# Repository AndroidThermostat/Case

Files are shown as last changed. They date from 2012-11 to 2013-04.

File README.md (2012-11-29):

Case
====

A printable 3d model of a case that can be used with the Android Thermostat project.

**Important** Make sure the case you print matches the revision number on the assembly instructions.

License
-------

CERN OPEN HARDWARE LICENCE v1.1

Preamble

Through this CERN Open Hardware Licence ("CERN OHL") version 1.1, the
Organization wishes to disseminate its hardware designs (as published
on http://www.ohwr.org/) as widely as possible, and generally to
foster collaboration among public research hardware designers.  The
CERN OHL is copyright of CERN. Anyone is welcome to use the CERN OHL,
in unmodified form only, for the distribution of his own Open Hardware
designs. Any other right is reserved.  

1 Definitions

In this Licence, the following terms have the following meanings:

“Licence” means this CERN OHL.  

“Documentation” means schematic diagrams, designs, circuit or circuit
board layouts, mechanical drawings, flow charts and descriptive text,
and other explanatory material that is explicitly stated as being made
available under the conditions of this Licence. The Documentation may
be in any medium, including but not limited to computer files and
representations on paper, film, or any other media.  

“Product” means either an entire, or any part of a, device built using
the Documentation or the modified Documentation.  

“Licensee” means any natural or legal person exercising rights under
this Licence.  

“Licensor” means any natural or legal person that creates or modifies
Documentation and subsequently communicates to the public and/ or
distributes the resulting Documentation under the terms and conditions
of this Licence.  

A Licensee may at the same time be a Licensor, and vice versa.

2 Applicability

2.1 This Licence governs the use, copying, modification, communication
to the public and distribution of the Documentation, and the
manufacture and distribution of Products. By exercising any right
granted under this Licence, the Licensee irrevocably accepts these
terms and conditions.  

2.2 This Licence is granted by the Licensor directly to the Licensee,
and shall apply worldwide and without limitation in time. The Licensee
may assign his licence rights or grant sub-licences.  

2.3 This Licence does not apply to software, firmware, or code loaded
into programmable devices which may be used in conjunction with the
Documentation, the modified Documentation or with Products. The use of
such software, firmware, or code is subject to the applicable licence
terms and conditions.  

3 Copying, modification, communication to the public and distribution
of the Documentation

3.1 The Licensee shall keep intact all copyright and trademarks
notices and all notices that refer to this Licence and to the
disclaimer of warranties that is included in the Documentation. He
shall include a copy thereof in every copy of the Documentation or, as
the case may be, modified Documentation, that he communicates to the
public or distributes.

3.2 The Licensee may use, copy, communicate to the public and
distribute verbatim copies of the Documentation, in any medium,
subject to the requirements specified in section 3.1.

3.3 The Licensee may modify the Documentation or any portion
thereof. The Licensee may communicate to the public and distribute the
modified Documentation (thereby in addition to being a Licensee also
becoming a Licensor), always provided that he shall: 
a. comply with section 3.1;
b. cause the modified Documentation to carry prominent notices stating
that the Licensee has modified the Documentation, with the date and
details of the modifications;
c. license the modified Documentation under the terms and conditions
of this Licence or, where applicable, a later version of this Licence
as may be issued by CERN; and
d. send a copy of the modified Documentation to all Licensors that
contributed to the parts of the Documentation that were modified, as
well as to any other Licensor who has requested to receive a copy of
the modified Documentation and has provided a means of contact with
the Documentation.

3.4 The Licence includes a licence to those patents or registered
designs that are held by the Licensor, to the extent necessary to make
use of the rights granted under this Licence. The scope of this
section 3.4 shall be strictly limited to the parts of the
Documentation or modified Documentation created by the Licensor.

4 Manufacture and distribution of Products

4.1 The Licensee may manufacture or distribute Products always
provided that the Licensee distributes to each recipient of such
Products a copy of the Documentation or modified Documentation, as
applicable, and complies with section 3.

4.2 The Licensee is invited to inform in writing any Licensor who has
indicated its wish to receive this information about the type,
quantity and dates of production of Products the Licensee has (had)
manufactured.

5 Warranty and liability

5.1 DISCLAIMER – The Documentation and any modified Documentation are
provided "as is" and any express or implied warranties, including, but
not limited to, implied warranties of merchantability, of satisfactory
quality, and fitness for a particular purpose or use are disclaimed in
respect of the Documentation, the modified Documentation or any
Product. The Licensor makes no representation that the Documentation,
modified Documentation, or any Product, does or will not infringe any
patent, copyright, trade secret or other proprietary right. The entire
risk as to the use, quality, and performance of a Product shall be
with the Licensee and not the Licensor. This disclaimer of warranty is
an essential part of this Licence and a condition for the grant of any
rights granted under this Licence. The Licensee warrants that it does
not act in a consumer capacity.

5.2 LIMITATION OF LIABILITY – The Licensor shall have no liability for
direct, indirect, special, incidental, consequential, exemplary,
punitive or other damages of any character including, without
limitation, procurement of substitute goods or services, loss of use,
data or profits, or business interruption, however caused and on any
theory of contract, warranty, tort (including negligence), product
liability or otherwise, arising in any way in relation to the
Documentation, modified Documentation and/or the use, manufacture or
distribution of a Product, even if advised of the possibility of such
damages, and the Licensee shall hold the Licensor(s) free and harmless
from any liability, costs, damages, fees and expenses, including
claims by third parties, in relation to such use.

6 General

6.1 The rights granted under this Licence do not imply or represent
any transfer or assignment of intellectual property rights to the
Licensee.

6.2 The Licensee shall not use or make reference to any of the names,
acronyms, images or logos under which the Licensor is known, save in
so far as required to comply with section 3. Any such permitted use or
reference shall be factual and shall in no event suggest any kind of
endorsement by the Licensor or its personnel of the modified
Documentation or any Product, or any kind of implication by the
Licensor or its personnel in the preparation of the modified
Documentation or Product.

6.3 CERN may publish updated versions of this Licence which retain the
same general provisions as this version, but differ in detail so far
this is required and reasonable. New versions will be published with a
unique version number.

6.4 This Licence shall terminate with immediate effect, upon written
notice and without involvement of a court if the Licensee fails to
comply with any of its terms and conditions, or if the Licensee
initiates legal action against Licensor in relation to this
Licence. Section 5 shall continue to apply.

6.5 Except as may be otherwise agreed with the Intergovernmental
Organization, any dispute with respect to this Licence involving an
Intergovernmental Organization shall, by virtue of the latter's
Intergovernmental status, be settled by international arbitration. The
arbitration proceedings shall be held at the place where the
Intergovernmental Organization has its seat. The arbitral award shall
be final and binding upon the parties, who hereby expressly agree to
renounce any form of appeal or revision.

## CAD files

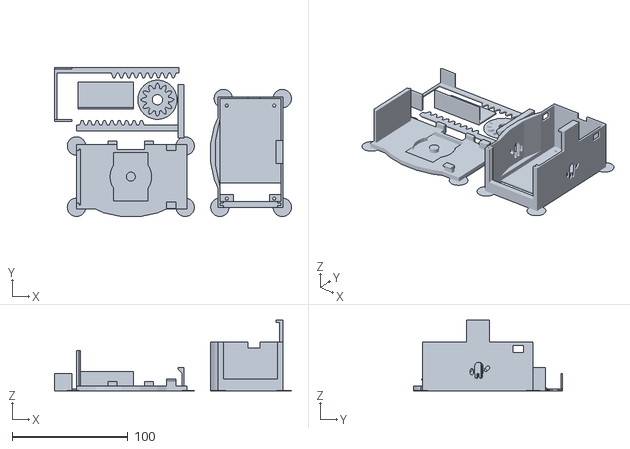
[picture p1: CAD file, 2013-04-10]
Revision B/STL/Full.stl
204.9 x 129.1 x 61.0

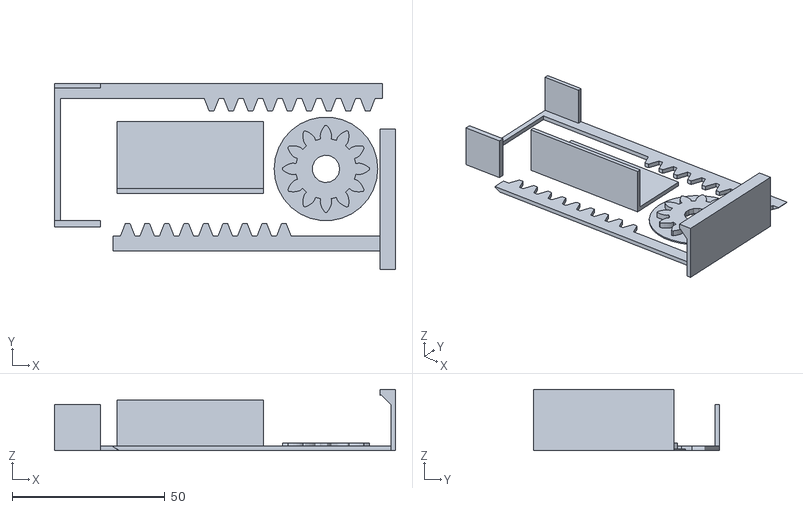
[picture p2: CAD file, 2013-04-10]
Revision B/STL/Rack.stl
111.8 x 61.0 x 20.0

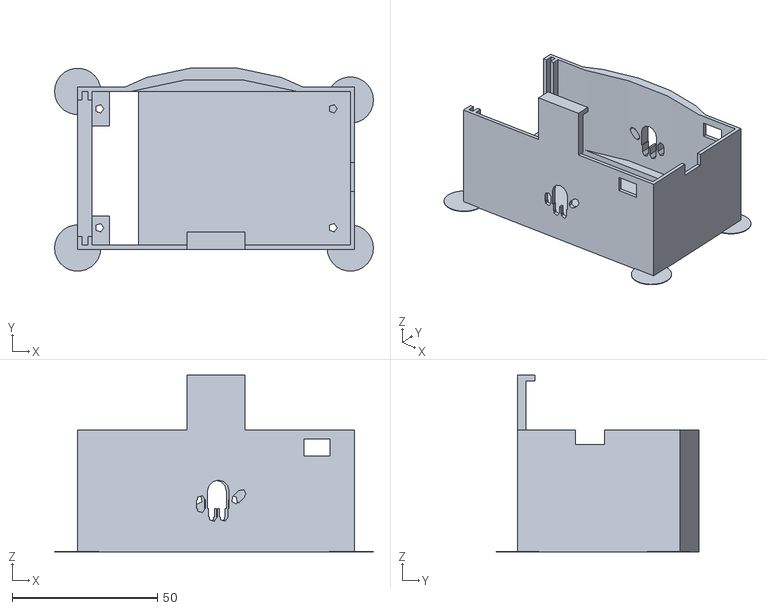
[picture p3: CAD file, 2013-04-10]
Revision B/STL/Case.stl
110.0 x 70.0 x 61.0

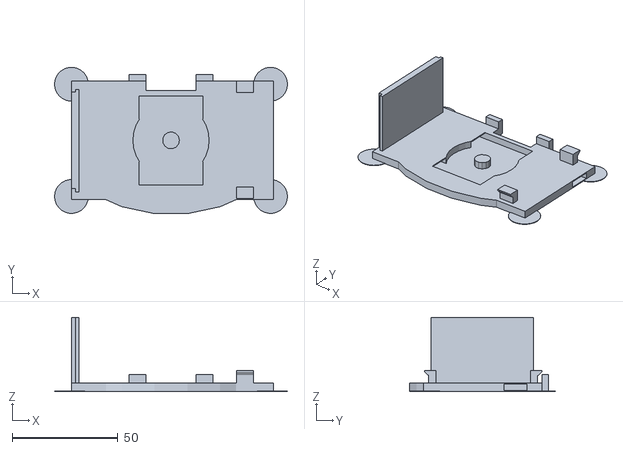
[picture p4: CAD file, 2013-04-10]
Revision B/STL/Lid.stl
110.0 x 69.0 x 35.0

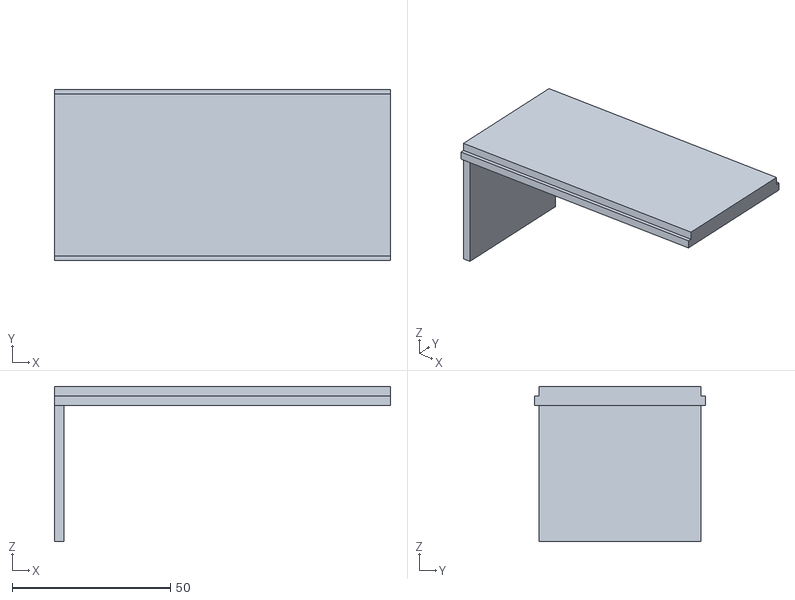
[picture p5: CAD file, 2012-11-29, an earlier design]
Revision A/CaseTop.stl
106.0 x 54.0 x 49.0

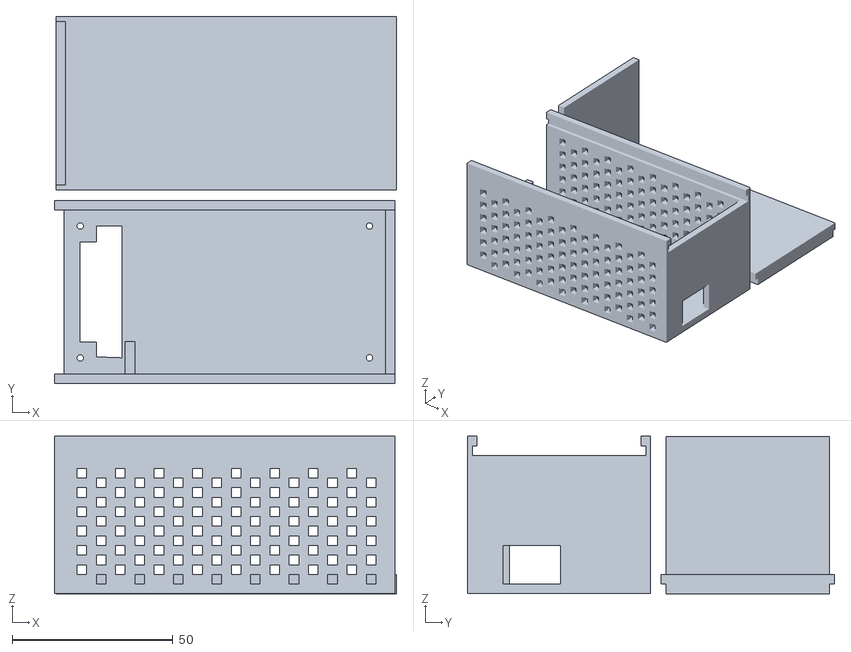
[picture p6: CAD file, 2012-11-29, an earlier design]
Revision A/CaseBoth.stl
106.4 x 114.2 x 49.0

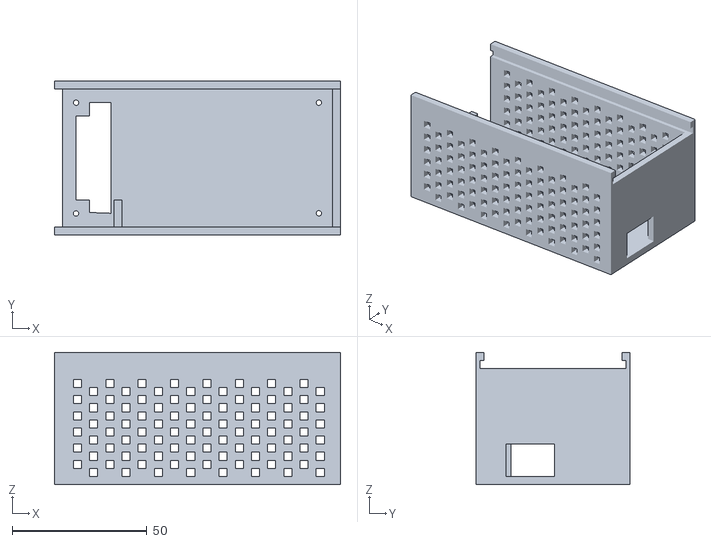
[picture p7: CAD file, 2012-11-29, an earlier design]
Revision A/CaseBottom.stl
106.0 x 57.0 x 49.0

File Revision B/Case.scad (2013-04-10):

include <gearLib.scad>

caseLength=94;
caseWidth=53;
caseHeight = 42; //36
wallThickness = 1.5;

//**********************************Lid***************************************************
module drawLidBase(x,y,z)
{
	translate([x, y-wallThickness, z]) cube([caseLength + wallThickness,caseWidth + (wallThickness*2),4]);

	//pads to help prevent pealing
	translate([x, y, z]) cylinder(h = 0.2,r = 8);
	translate([x, y+caseWidth, z]) cylinder(h = 0.2,r = 8);
	translate([x+caseLength, y, z]) cylinder(h = 0.2,r = 8);
	translate([x+caseLength, y+caseWidth, z]) cylinder(h = 0.2,r = 8);

	//lip
	translate([x+2, y+2, z+4]) cube ([1.5,caseWidth-4.5,caseHeight-11]);
	translate([x, y+3.75, z+4]) cube ([2,caseWidth-7.5,caseHeight-11]);


	//Catches
	difference()
	{
		translate([x+caseLength-16,y-1,z+4]) cube([8,5.5,6]);
		translate([x+caseLength-16,y-1,z+4]) cube([8,2,3.9]);
		translate([x+caseLength-16,y-1.7,z+5.8]) rotate([45,0,0]) cube([8,3,3]);
	}

	difference()
	{
		translate([x+caseLength-16,y + caseWidth - 4,z+4]) cube([8,5.5,6]);
		translate([x+caseLength-16,y + caseWidth - 0.5,z+4]) cube([8,2,3.5]);
		translate([x+caseLength-16,y + caseWidth + 1.7, z+5.4]) rotate([45,0,0]) cube([8,3,3]);
	}

	//draw the curved top
	difference()
	{
		translate([x+caseLength/2,y+caseWidth+13.7,z]) cylinder(h = 4,r = caseLength*0.8);
		translate([x-caseLength/2,y-caseLength+100,z]) cube([caseLength*2,caseLength*2+10,4]);
	}

	translate([x+(caseLength+23.5)/2,  y+ caseWidth+wallThickness , z]) cube([8,3,8]);
	translate([x+(caseLength-23.5)/2-8,  y+ caseWidth+wallThickness , z]) cube([8,3,8]);
}

module drawLidCutouts(x,y,z)
{
	//Gear hole
	translate([x+(caseLength/2), y+(caseWidth/2), z+0.5]) cylinder(h = 3.5,r = 18);

	//Top Rail
	translate([x, y+(caseWidth/2 - 21), z+0.5]) cube([caseLength-wallThickness,11,3]);
	translate([x+(caseLength-30)/2, y+(caseWidth/2 - 21), z+3]) cube([30,11,1]);

	//Bottom Rail
	translate([x+5, y+(caseWidth/2 + 10), z+0.5]) cube([caseLength-wallThickness,11,3]);
	translate([x+(caseLength-30)/2, y+(caseWidth/2 + 10), z+3]) cube([30,11,1]);

	//Cutout for lip
	translate([x+(caseLength-23.5)/2, y+ caseWidth - 3, z]) cube([23.5,4.5,4]);
}

module drawLid(x,y,z)
{
	difference()
	{
		drawLidBase(x,y,z);
		drawLidCutouts(x,y,z);
	}
	translate([x+(caseLength/2),y+(caseWidth/2),z+0.5]) cylinder(h = 3.5,r = 4);
}



//*****************************Rack and Pinion*******************************************

module drawGear(x,y,z)
{
	difference() 
	{
		translate([x,y,z]) cylinder(h = 0.5,r = 17);
		translate([x,y,z]) cylinder(h = 0.5,r = 5);
	}
	//12.23 radius  -   circular_pitch * number_of_teeth / 360
	translate([x, y, z+0.5]) gear(number_of_teeth=12, circular_pitch=367, hub_thickness=0, bore_diameter=9,rim_thickness=2, gear_thickness=2);
}

module drawLeftRack(x,y,z)
{
	//mm_per_tooth = 2 * Pi * r / gear_teeth
	difference()
	{
		translate([x+caseLength-106,y,z+(1.5/2)]) rack(height=9, mm_per_tooth=6.4, number_of_teeth=9, thickness=wallThickness);
		translate([x+caseLength-106-7.5,y-7,z+1.5-4.5]) rotate([0,30,0])  cube ([5,5,5]); //Angle tip
		//translate([x,y,z+(1.5/2)]) rack(height=9, mm_per_tooth=6.4, number_of_teeth=9, thickness=wallThickness);
		//translate([x-7.5,y-7,z+1.5-4.5]) rotate([0,30,0])  cube ([5,5,5]); //Angle tip
	}

	translate([x+(caseLength-50),y-7,z]) cube([(caseLength-63.7),5,wallThickness]);
	translate([x+(caseLength-50 + caseLength-63.7),y-8-5,z]) cube([wallThickness,46,15]);
	difference(){
		translate([x+(caseLength-50 + caseLength-63.7)-5+wallThickness,y-8-5,z+15]) cube([5,46,5]);
		translate([x+(caseLength-50 + caseLength-63.7)-wallThickness,y-8-5,z+13]) rotate([0,315,0]) cube([2.5,46,5]);
	}
}

module drawRightRackCap(x,y,z)
{
	translate([x+5,y-49.5,z]) cube([23.5,48,1.5]);
	translate([x+5,y-49.5,z+1.5]) cube([1.5,48,15]);
}

module drawRightRack(x,y,z)
{
	difference()
	{
		translate([x+(caseLength-6.3),y,z+(1.5/2)]) rotate([0,0,180]) rack(height=9, mm_per_tooth=6.4, number_of_teeth=9, thickness=wallThickness);
		translate([x+(caseLength-3.8),y,z]) rotate([0,60,0])  cube ([5,15,5]); //Angle tip
	}


	translate([x,y+2,z]) cube([caseLength-59.7,5,1.5]);

	difference()
	{
		translate([x-15,y-51+11,z]) cube([15,47,15]);
		translate([x-15,y-51+13,z+wallThickness]) cube([15,43.5,78]);
		translate([x-13,y-51+13,z]) cube([13,40,8]);
	}

}





//*****************************Case***************************************************

module drawLogo(x,y,z)
{
	union() {
		translate([x,y,z])  rotate([90,0,0]) cylinder(h = wallThickness*4,r = 3.75);

		translate([x-3.75,y-wallThickness*4,z-6])  cube([7.5,wallThickness*4,6]);
		translate([x-6,y,z-3])  rotate([90,0,0]) drawLogoExtremity();
		translate([x-1.875,y,z-6])  rotate([90,0,0]) drawLogoExtremity();
		translate([x+1.875,y,z-6])  rotate([90,0,0]) drawLogoExtremity();
		translate([x+6,y,z-3])  rotate([90,225,0]) drawLogoExtremity();
	}
}

module drawLogoExtremity()
{
	cylinder(h = wallThickness*4,r = 1.5);
	translate([-1.5,-3,0]) cube([3,3,wallThickness*4]);
	translate([0,-3,0]) cylinder(h = wallThickness*4,r = 1.5);
}

module drawCase(x,y,z)
{
	stepsH=(caseHeight-11)/6;
	stepsL=(caseLength-12)/12;

	//pads to help prevent pealing
	translate([x, y+2, z]) cylinder(h = 0.2,r = 8);
	translate([x+caseLength, y+2, z]) cylinder(h = 0.2,r = 8);
	translate([x, y+caseWidth+(wallThickness*2), z]) cylinder(h = 0.2,r = 8);
	translate([x+caseLength, y+caseWidth, z]) cylinder(h = 0.2,r = 8);

	difference()
	{
		//Bottom and screw holes
		translate([x,y+(wallThickness*2),z]) cube([caseLength,caseWidth,wallThickness]);

		translate([x+wallThickness+6,y+(wallThickness*2)+6,z]) cylinder(h = wallThickness,r = 1.5);
		translate([x+wallThickness+6,y+caseWidth+(wallThickness*2)-6,z]) cylinder(h = wallThickness,r = 1.5);
		translate([x+caseLength-6,y+(wallThickness*2)+6,z]) cylinder(h = wallThickness,r = 1.5);
		translate([x+caseLength-6,y+caseWidth+(wallThickness*2)-6,z]) cylinder(h = wallThickness,r = 1.5);

		//Hole for furnace wires
		translate([x+(wallThickness*2),y+13,z]) cube([8,31,wallThickness]);
		translate([x+(wallThickness*2)+8,y+(wallThickness*2),z]) cube([10,caseWidth,wallThickness]);
	}


	//Side walls
	difference() {
		union(){
			translate([x,y+wallThickness,z]) cube([caseLength,wallThickness,caseHeight]);
			translate([x,y+caseWidth+(wallThickness*2),z]) cube([caseLength,wallThickness,caseHeight]);

			//draw the curved top
			difference()
			{
				translate([x+caseLength/2,y-10.7,z]) cylinder(h = caseHeight,r = caseLength*0.8);
				translate([x-caseLength/2,y-caseLength-(caseLength/2),z]) cube([caseLength*2,caseLength*2+10,caseHeight]);
			}
		}

		//Cut away the inside of the curved top
		difference()
		{
//			translate([x+caseLength/2,y-32-wallThickness,z+wallThickness]) cylinder(h = caseHeight-wallThickness,r = caseLength);
			translate([x+caseLength/2,y-32-wallThickness,z+wallThickness+4]) cylinder(h = caseHeight-wallThickness,r = caseLength);
			translate([x-caseLength/2,y-caseLength-(caseLength/2)-wallThickness,z]) cube([caseLength*2,caseLength*2+10,caseHeight]);
		}


		drawLogo(x+(caseLength/2)+1.5,y+4,z+(wallThickness*2)+18);
		rotate([0,0,180]) drawLogo(-x-(caseLength/2)-0.5,-y-caseWidth-wallThickness*2-3,z+(wallThickness*2)+18);

		//Lid catches		
		 translate([x+caseLength-16,y,z+caseHeight-9]) cube([9,3,6]);
		 translate([x+caseLength-16,y+caseWidth+(wallThickness*2),z+caseHeight-9]) cube([9,3,6]);
	}

	//board catch	
//	translate([x,y+caseWidth+(wallThickness*2),z]) cube([caseLength,wallThickness,8]);

	//back wall
	difference()
	{
		translate([x+caseLength,y+wallThickness,z]) cube([wallThickness,caseWidth+(wallThickness*2),caseHeight]);
		translate([x+caseLength,y+(caseWidth-10)/2, caseHeight-5]) cube([wallThickness,10,5]);
//		translate([x+caseLength-wallThickness,y+caseWidth/2,caseHeight-4]) rotate([0,90,0]) cylinder(h = wallThickness*2,r = 4);
	}


	//Lip
	difference()
	{
		translate([x+(caseLength-18.5)/2,y+wallThickness,z+caseHeight-wallThickness]) cube([20,wallThickness*2,17+wallThickness]);
		translate([x+(caseLength-18.5)/2,y+wallThickness*2+1,z+caseHeight-wallThickness-1]) rotate([45,0,0]) cube([20,wallThickness*2,wallThickness]);
	}

	translate([x+(caseLength-18.5)/2,y+wallThickness,z+caseHeight+17]) cube([20,3*2,2]);

	//Grooves
	difference()
	{
		translate([x,y+(wallThickness*2),z]) cube([5,3,caseHeight]);
		translate([x+wallThickness,y+(wallThickness*2),z]) cube([2,3,caseHeight]);
	}
	difference()
	{
		translate([x,y+caseWidth,z]) cube([5,3,caseHeight]);
		translate([x+wallThickness,y+caseWidth,z]) cube([2,3,caseHeight]);
	}

	translate([x,y+(wallThickness*2),z]) cube([5,caseWidth,10]);

}








//*****************************Combinations**********************************************


module drawAssembled(x,y,z)
{
	drawCase(x,y,z);
	rotate([180,0,0]) drawLidAssembled(x,y-54,-z - 40);
}
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

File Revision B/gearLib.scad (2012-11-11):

// Parametric Involute Bevel and Spur Gears by GregFrost
// It is licensed under the Creative Commons - GNU GPL license.
// © 2010 by GregFrost
// http://www.thingiverse.com/thing:3575

// Simple Test:
//gear (circular_pitch=700,
//	gear_thickness = 12,
//	rim_thickness = 15,
//	hub_thickness = 17,
//	circles=8);

//Complex Spur Gear Test:
//test_gears ();

// Meshing Double Helix:
//meshing_double_helix ();

// Demonstrate the backlash option for Spur gears.
//test_backlash ();

// Demonstrate how to make meshing bevel gears.
//bevel_gear_pair ();

pi=3.1415926535897932384626433832795;

//==================================================
// Bevel Gears:
// Two gears with the same cone distance, circular pitch (measured at the cone distance) 
// and pressure angle will mesh.

module bevel_gear_pair (
	gear1_teeth = 41,
	gear2_teeth = 7,
	axis_angle = 90,
	outside_circular_pitch=1000)
{
	outside_pitch_radius1 = gear1_teeth * outside_circular_pitch / 360;
	outside_pitch_radius2 = gear2_teeth * outside_circular_pitch / 360;
	pitch_apex1=outside_pitch_radius2 * sin (axis_angle) + 
		(outside_pitch_radius2 * cos (axis_angle) + outside_pitch_radius1) / tan (axis_angle);
	cone_distance = sqrt (pow (pitch_apex1, 2) + pow (outside_pitch_radius1, 2));
	pitch_apex2 = sqrt (pow (cone_distance, 2) - pow (outside_pitch_radius2, 2));
	echo ("cone_distance", cone_distance);
	pitch_angle1 = asin (outside_pitch_radius1 / cone_distance);
	pitch_angle2 = asin (outside_pitch_radius2 / cone_distance);
	echo ("pitch_angle1, pitch_angle2", pitch_angle1, pitch_angle2);
	echo ("pitch_angle1 + pitch_angle2", pitch_angle1 + pitch_angle2);

	rotate([0,0,90])
	translate ([0,0,pitch_apex1+20])
	{
		translate([0,0,-pitch_apex1])
		bevel_gear (
			number_of_teeth=gear1_teeth,
			cone_distance=cone_distance,
			pressure_angle=30,
			outside_circular_pitch=outside_circular_pitch);
	
		rotate([0,-(pitch_angle1+pitch_angle2),0])
		translate([0,0,-pitch_apex2])
		bevel_gear (
			number_of_teeth=gear2_teeth,
			cone_distance=cone_distance,
			pressure_angle=30,
			outside_circular_pitch=outside_circular_pitch);
	}
}

//Bevel Gear Finishing Options:
bevel_gear_flat = 0;
bevel_gear_back_cone = 1;

module bevel_gear (
	number_of_teeth=11,
	cone_distance=100,
	face_width=20,
	outside_circular_pitch=1000,
	pressure_angle=30,
	clearance = 0.2,
	bore_diameter=5,
	gear_thickness = 15,
	backlash = 0,
	involute_facets=0,
	finish = -1)
{
	echo ("bevel_gear",
		"teeth", number_of_teeth,
		"cone distance", cone_distance,
		face_width,
		outside_circular_pitch,
		pressure_angle,
		clearance,
		bore_diameter,
		involute_facets,
		finish);

	// Pitch diameter: Diameter of pitch circle at the fat end of the gear.
	outside_pitch_diameter  =  number_of_teeth * outside_circular_pitch / 180;
	outside_pitch_radius = outside_pitch_diameter / 2;

	// The height of the pitch apex.
	pitch_apex = sqrt (pow (cone_distance, 2) - pow (outside_pitch_radius, 2));
	pitch_angle = asin (outside_pitch_radius/cone_distance);

	echo ("Num Teeth:", number_of_teeth, " Pitch Angle:", pitch_angle);

	finish = (finish != -1) ? finish : (pitch_angle < 45) ? bevel_gear_flat : bevel_gear_back_cone;

	apex_to_apex=cone_distance / cos (pitch_angle);
	back_cone_radius = apex_to_apex * sin (pitch_angle);

	// Calculate and display the pitch angle. This is needed to determine the angle to mount two meshing cone gears.

	// Base Circle for forming the involute teeth shape.
	base_radius = back_cone_radius * cos (pressure_angle);	

	// Diametrial pitch: Number of teeth per unit length.
	pitch_diametrial = number_of_teeth / outside_pitch_diameter;

	// Addendum: Radial distance from pitch circle to outside circle.
	addendum = 1 / pitch_diametrial;
	// Outer Circle
	outer_radius = back_cone_radius + addendum;

	// Dedendum: Radial distance from pitch circle to root diameter
	dedendum = addendum + clearance;
	dedendum_angle = atan (dedendum / cone_distance);
	root_angle = pitch_angle - dedendum_angle;

	root_cone_full_radius = tan (root_angle)*apex_to_apex;
	back_cone_full_radius=apex_to_apex / tan (pitch_angle);

	back_cone_end_radius = 
		outside_pitch_radius - 
		dedendum * cos (pitch_angle) - 
		gear_thickness / tan (pitch_angle);
	back_cone_descent = dedendum * sin (pitch_angle) + gear_thickness;

	// Root diameter: Diameter of bottom of tooth spaces.
	root_radius = back_cone_radius - dedendum;

	half_tooth_thickness = outside_pitch_radius * sin (360 / (4 * number_of_teeth)) - backlash / 4;
	half_thick_angle = asin (half_tooth_thickness / back_cone_radius);

	face_cone_height = apex_to_apex-face_width / cos (pitch_angle);
	face_cone_full_radius = face_cone_height / tan (pitch_angle);
	face_cone_descent = dedendum * sin (pitch_angle);
	face_cone_end_radius = 
		outside_pitch_radius -
		face_width / sin (pitch_angle) - 
		face_cone_descent / tan (pitch_angle);

	// For the bevel_gear_flat finish option, calculate the height of a cube to select the portion of the gear that includes the full pitch face.
	bevel_gear_flat_height = pitch_apex - (cone_distance - face_width) * cos (pitch_angle);

//	translate([0,0,-pitch_apex])
	difference ()
	{
		intersection ()
		{
			union()
			{
				rotate (half_thick_angle)
				translate ([0,0,pitch_apex-apex_to_apex])
				cylinder ($fn=number_of_teeth*2, r1=root_cone_full_radius,r2=0,h=apex_to_apex);
				for (i = [1:number_of_teeth])
//				for (i = [1:1])
				{
					rotate ([0,0,i*360/number_of_teeth])
					{
						involute_bevel_gear_tooth (
							back_cone_radius = back_cone_radius,
							root_radius = root_radius,
							base_radius = base_radius,
							outer_radius = outer_radius,
							pitch_apex = pitch_apex,
							cone_distance = cone_distance,
							half_thick_angle = half_thick_angle,
							involute_facets = involute_facets);
					}
				}
			}

			if (finish == bevel_gear_back_cone)
			{
				translate ([0,0,-back_cone_descent])
				cylinder (
					$fn=number_of_teeth*2, 
					r1=back_cone_end_radius,
					r2=back_cone_full_radius*2,
					h=apex_to_apex + back_cone_descent);
			}
			else
			{
				translate ([-1.5*outside_pitch_radius,-1.5*outside_pitch_radius,0])
				cube ([3*outside_pitch_radius,
					3*outside_pitch_radius,
					bevel_gear_flat_height]);
			}
		}
		
		if (finish == bevel_gear_back_cone)
		{
			translate ([0,0,-face_cone_descent])
			cylinder (
				r1=face_cone_end_radius,
				r2=face_cone_full_radius * 2,
				h=face_cone_height + face_cone_descent+pitch_apex);
		}

		translate ([0,0,pitch_apex - apex_to_apex])
		cylinder (r=bore_diameter/2,h=apex_to_apex);
	}	
}

module involute_bevel_gear_tooth (
	back_cone_radius,
	root_radius,
	base_radius,
	outer_radius,
	pitch_apex,
	cone_distance,
	half_thick_angle,
	involute_facets)
{
//	echo ("involute_bevel_gear_tooth",
//		back_cone_radius,
//		root_radius,
//		base_radius,
//		outer_radius,
//		pitch_apex,
//		cone_distance,
//		half_thick_angle);

	min_radius = max (base_radius*2,root_radius*2);

	pitch_point = 
		involute (
			base_radius*2, 
			involute_intersect_angle (base_radius*2, back_cone_radius*2));
	pitch_angle = atan2 (pitch_point[1], pitch_point[0]);
	centre_angle = pitch_angle + half_thick_angle;

	start_angle = involute_intersect_angle (base_radius*2, min_radius);
	stop_angle = involute_intersect_angle (base_radius*2, outer_radius*2);

	res=(involute_facets!=0)?involute_facets:($fn==0)?5:$fn/4;

	translate ([0,0,pitch_apex])
	rotate ([0,-atan(back_cone_radius/cone_distance),0])
	translate ([-back_cone_radius*2,0,-cone_distance*2])
	union ()
	{
		for (i=[1:res])
		{
			assign (
				point1=
					involute (base_radius*2,start_angle+(stop_angle - start_angle)*(i-1)/res),
				point2=
					involute (base_radius*2,start_angle+(stop_angle - start_angle)*(i)/res))
			{
				assign (
					side1_point1 = rotate_point (centre_angle, point1),
					side1_point2 = rotate_point (centre_angle, point2),
					side2_point1 = mirror_point (rotate_point (centre_angle, point1)),
					side2_point2 = mirror_point (rotate_point (centre_angle, point2)))
				{
					polyhedron (
						points=[
							[back_cone_radius*2+0.1,0,cone_distance*2],
							[side1_point1[0],side1_point1[1],0],
							[side1_point2[0],side1_point2[1],0],
							[side2_point2[0],side2_point2[1],0],
							[side2_point1[0],side2_point1[1],0],
							[0.1,0,0]],
						triangles=[[0,1,2],[0,2,3],[0,3,4],[0,5,1],[1,5,2],[2,5,3],[3,5,4],[0,4,5]]);
				}
			}
		}
	}
}

module gear (
	number_of_teeth=15,
	circular_pitch=false, diametral_pitch=false,
	pressure_angle=28,
	clearance = 0.2,
	gear_thickness=5,
	rim_thickness=8,
	rim_width=5,
	hub_thickness=10,
	hub_diameter=15,
	bore_diameter=5,
	circles=0,
	backlash=0,
	twist=0,
	involute_facets=0)
{
	if (circular_pitch==false && diametral_pitch==false) 
		echo("MCAD ERROR: gear module needs either a diametral_pitch or circular_pitch");

	//Convert diametrial pitch to our native circular pitch
	circular_pitch = (circular_pitch!=false?circular_pitch:180/diametral_pitch);
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

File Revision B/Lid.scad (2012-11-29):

include <gearLib.scad>


//**********************************Lid***************************************************
module lidBase(x,y,z)
{
	translate([x,y,z]) cube([106,51,1.5]);
	translate([x, y-1.5, z+1.5]) cube([106,54,2.5]);
	translate([x, y, z+1.5]) cube ([1.5,51,45]);
}

module lidCutouts(x,y,z)
{
	translate([x+53, y+25.5, z+1.5]) cylinder(h = 2.5,r = 18);
	translate([x, y+5, z+1.5]) cube([101,12,2]);
	translate([x+5, y+49-12, z+1.5]) cube([101,12,2]);
}

module lid(x,y,z)
{
	difference()
	{
		lidBase(x,y,z);
		lidCutouts(x,y,z);
	}
	translate([x+53,y+25.5,z+1.5]) cylinder(h = 1.5,r = 4);
}



//*****************************Rack and Pinion*******************************************

module drawGear(x,y,z)
{
	difference() 
	{
		translate([x,y,z]) cylinder(h = 0.5,r = 17);
		translate([x,y,z]) cylinder(h = 0.5,r = 5);
	}
	//14.5 radius
	translate([x, y, z+0.5]) gear(number_of_teeth=11, circular_pitch=400, hub_thickness=0, bore_diameter=9,rim_thickness=2, gear_thickness=2);
}

module drawLeftRack(x,y,z)
{
	translate([x,y,z+(1.5/2)]) rack(height=10, mm_per_tooth=6.2, number_of_teeth=13, thickness=1.5);
	translate([x+79,y-8.1,z]) cube([22,6,1.5]);
	translate([x+101,y-8-5,z]) cube([1.5,46,10]);
}

module drawRightRack(x,y,z)
{
	translate([x+22+79,y,z+(1.5/2)]) rotate([0,0,180]) rack(height=10, mm_per_tooth=6.2, number_of_teeth=13, thickness=1.5);
	translate([x,y+2,z]) cube([22,6,1.5]);
	difference()
	{
		translate([x-9,y-51+11,z]) cube([9,48,10]);
		translate([x-7.5,y-51+13,z+2]) cube([7.5,44,6]);
		translate([x-7.5,y-51+13,z]) cube([6,40,8]);
	}
}





//*****************************Case***************************************************


module drawCase(x,y,z)
{
	height=47;
	length=104.5;

	stepsH=(height-16)/6;
	stepsL=(length-12)/12;

	difference()
	{
		translate([x+1.5,y+3,z]) cube([104.5,51,1.5]);
		translate([x+1.5+5,y+3+5,z]) cylinder(h = 1.5,r = 1);
		translate([x+1.5+5,y+51+3-5,z]) cylinder(h = 1.5,r = 1);
		translate([x+1.5+104.5-5,y+3+5,z]) cylinder(h = 1.5,r = 1);
		translate([x+1.5+104.5-5,y+51+3-5,z]) cylinder(h = 1.5,r = 1);
		translate([x+3,y+11,z]) cube([6,35,1.5]);
		translate([x+3+6,y+3,z]) cube([12,51,1.5]);
	}
	translate([x+21,y+51-10+3,z+1.5]) cube([3,10,3]);

	difference() {
		union(){
			translate([x,y,z]) cube([106,3,height]);
			translate([x,y+54,z]) cube([106,3,height]);
		}
		for(iL=[0:stepsL])
		{
			for(iH=[0:stepsH])
			{
				//first wall
				translate([x+6 + iL*12,y,z+3 + iH*6]) cube([3,3,3]);
				translate([x+6 + iL*12 + 6,y,z+6 + iH*6]) cube([3,3,3]);
				//second wall
				translate([x+6 + iL*12,y+54,z+3 + iH*6]) cube([3,3,3]);
				translate([x+6 + iL*12 + 6,y+54,z+6 + iH*6]) cube([3,3,3]);
			}
		}
		translate([x,y+1.5,z+43]) cube([106,1.5,2.5]);
		translate([x,y+54,z+43]) cube([106,1.5,2.5]);
	}
	difference()
	{
		translate([x+106,y,z]) cube([1.5,57,43]);
		translate([x+106,y+23,39]) cube([1.5,10,4]);
	}
	translate([x+(length-20)/2,y,z+height]) cube([20,3,10]);
	translate([x+(length-20)/2,y,z+height+10]) cube([20,5,2]);
}








//*****************************Combinations**********************************************


module drawAssembled(x,y,z)
{
	drawCase(x,y,z);
	rotate([180,0,0]) drawLidAssembled(x,y-54.5,-z - 47);
}

module drawLidAssembled(x,y,z)
{
	lid(x,y,z);
	drawGear(x + 53, y+25.5, z+1.5);
	rotate([0,180,0]) drawLeftRack(-x-96, y+14, -z-3.5);
	rotate([0,180,0]) drawRightRack(-x-111, y+37, -z-3.5);
}

module drawExploded(x,y,z)
{
	% translate([x,y,z-1]) cube([180,150,1]);
	lid(x,y,z);
	drawLeftRack(x+5, y+80, z);
	drawGear(x + 53, y+105, z);
	rotate([270,0,0]) drawRightRack(x+10, -z - 8, y+130);
	rotate([0,0,90]) drawCase(y,-x-170,z);
}



drawAssembled(0, 0, 0);
drawExploded(0, 100, 0);

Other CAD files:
Revision A/Case.skp

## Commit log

2012-11-11 Designs from 11/10/2012 Startup weekend.
    [gear.scad, gearAndRack.scad, gearLib.scad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]
2012-11-11 Better and more modular rack and pinion
    [gearLib.scad, thermo_case.scad]
2012-11-13 Case lid with cutouts and new gear
    [CaseLid.scad]
2012-11-13 Lid with no cutouts
    Used by the case lid file.
    [CaseTop.stl]
2012-11-13 Added "bridges" to the lid
    [CaseLid.scad, CaseLid.stl]
2012-11-13 Changed bore size to 8.5mm
    [gear.scad]
2012-11-29 Removed STL
    Drew the case lid from scratch instead of using an STL file.
    Reduced the wall sizes to save printing time and material.
    Added assembled and exploded views.
    Added USB cable compartment.
    Removed unused files.
    Organized designs by revision number.
    [Case.skp, CaseBoth.stl, CaseBottom.stl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]
2012-11-29 Reduced phone grip size
    Reduced the size of the phone grip so it can be printed vertically.
    [Lid.scad, gearLib.scad]
2012-11-29 Added Case
    Recreated the case as pure SCAD instead of STL.
    Fixed x,y,z issues with rotating.
    TODO: Add screw holes, wiring hole and IOIO brace to case.
    [Lid.scad]
2012-11-29 Added Ports
    Added screw holes in case.
    Added gap for furnace wires.
    Added wall to hold IOIO in place.
    [Lid.scad]
2012-12-03 Refined lid and arms
    Increased lid channel height.
    Tweaked pinion spacing
    Adjusted right arm layout.
    Split right arm into two peices.
    [Case.scad]
2012-12-04 Made Thinner
    Reduce the perforated walls from 3mm thick to 1.5mm
    Removed groove for lid in top and bottom walls.
    Added groove for lid in the left wall.
    Adjusted the spacing for the rack channels.
    Made racks thinner
    Removed tounge and groove for right rack cap.
    Squared off gear opening to help with briding issues while printing.
    [Case.scad]
2012-12-05 Fixed Lid Fit and Rack and Pinion
    Switch from 11 gears to 12
    Calculated the exact rack spacing
    Shortened the rack length to match channels
    Angled rack tip to slide into channels easier.
    Adjusted lid lip to fit case
    [Case.scad]
2012-12-06 Adjusted the lid fit.
    Moved the lid groove in an extra inch.
    Added catches to lid to help with bowing out problem.
    Renamed methods for drawing the lid
    Made the right rack and cap larger
    Made the case lip 4mm taller to account for the height of the lid.
    [Case.scad]
2012-12-19 Modified Lid Connection
    Added 1cm support to the open side of the case to prevent it from
    curling while printing.
    Widened lid clasps and the holes they go into.
    Shortened the opening for the lip
    [Case.scad]
2013-01-09 Final print tweaks
    Added pads to prevent pealing.
    Adjusted exploded layout.
    Printed and tested alignment.
    Cleaned up the code a bit.
    [Case.scad]
2013-02-11 Cleaned up
    I added parameters for case length, height, width and wall thickness and
    replaced many of the arbitraty numbers throughout the file with
    references to these varaibles.
    Also reduced the number of teeth in the arms from 13 to 9 since 4 of
    them would never be used and it'll print a little faster.
    [Case.scad]
2013-02-11 Resized Case
    Changed dimensions from 106x51mm to 94x53mm.
    Fixed places in code to queue off variables where they were not already
    doing so.
    Added new method to draw the rack & pinion components exploded.
    Removed the board catch
    Moved the screw holes to line up with the IOIO hole.
    [Case.scad]
2013-03-06 Exported STLs
    Exported STL files from SCAD
    [Case.scad, Case.stl, Lid.stl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]
2013-04-05 Rev B Final Commit
    Switched from perforated design to a curved top with logo holes on top
    and bottom to act more like a chimney to pull the heat out of the case.
    [Case.scad, Case.stl, Full.stl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]
2013-04-10 Made more sturdy
    Made the lip that holds the phone thicker and 3mm longer.
    Added lips to the left and right racks to prevent the phone from falling
    forward.
    Added two arms to the bottom side of the lid to prevent the bottom side
    of the case from bowing out under the weight of the phone.
    [Case.scad, Case.stl, Full.stl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]
2013-05-01 Added Alternative Case Design
